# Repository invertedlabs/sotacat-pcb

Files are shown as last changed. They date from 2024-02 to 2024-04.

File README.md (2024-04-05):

# SOTAcat PCB

This project creates a SOTAcat PCB designed in [KiCad](https://www.kicad.org) and compatible with Brian AB6D's [SOTAcat](https://github.com/SOTAmat/SOTAcat) and [SOTAMAT](https://sotamat.com/) ("SOTA-Mate") web service and software. Brian provides a cloud service and iOS and Android which can interface with SOTAcat hardware to command an Elecraft KX2 or KX3 to transmit SOTA or POTA spots from the field via the FT8 spotting networks.  [The SOTAcat software](https://github.com/SOTAmat/) by Brian and Jeff KC6X also has other great features like a web interface that polls SOTA and POTA spots from their respective databases and commands the KX2 or KX3 to the spot frequency and mode with a single click.

This repository contains hardware files only. These files are available in zipped gerber form under "releases" which can be uploaded to PCB board manufacturers like [OshPark](https://www.oshpark.com), [JLCPCB](https://www.jlcpcb.com), or [PCBWay](https://www.pcbway.com) for quick turn around prototype-quantity builds.

# Attribution

A lot of folks from the SOTA community have contributed to this project.  For full attribution, see [the attribution list](https://github.com/SOTAmat/SOTAcat?tab=readme-ov-file#attribution) in the software repository. 

Specifically, this project wouldn't have been possible without the great SOTAmat software and original SOTAcat concept by Brian Mathews AB6D, the SOTAcat software authored primarily by Brian and Jeff Kowalski KC6X, and timely feedback from Brian, Jeff, and Rex Vokey KE6MT during the hardware design phase.

# Bill of Materials

A full BOM will be uploaded in due time, for now, refer to the schematic documents for build information, including part numbers for ordering from suppliers like [DigiKey](https://www.digikey.com) or [Mouser](https://www.mouser.com).

# Batteries

SOTAcat is a battery powered device. The battery is charged via a USB-C port.  Under the hood, a Seeeed XIAO ESP32-C3 board provides the USB port and battery charging circuitry. The battery is charged at 350mA, which limits the battery selection to batteries that can safely accept this amount of current. Most single-cell batteries above 300mAh will do fine given the bettery isn't allowed to overheat when charging. While many LiPo batteries are limited to 1C charging, test show that with a 300mAh battery the time spent above 1C is very brief, generally less than 10 minutes with a fully dead battery. Even so, the PCB can get warm during the charging process, and steps should be made to keep the battery and PCB cool during charging. This can be done by keeping the thermal paths between the PCB and the battery to a miniumum (e.g. don't tape them directly together without an insulating layer), and only charging an enclosed device at room temperature (<80 deg F, or <27 deg C).  

As with all LiPo batteries, *always monitor the device while charging* and don't leave the device charging in very hot conditions such as a car on a warm day.

More information will be forthcoming about which batteries we have tested and recommend. If purchasing a battery, connectors have been provided on v0.3 for both TinyCircuits batteries and KBT batteries. Check the schematic and layout for pinout information.

# Antenna

A wifi antenna needs to be attached to the XIAO ESP32-C3 module using the U.FL connector on that PCB (between the buttons).  Most XIAO ESP32-C3 purchases will include a flexible WiFI antenna. Other antennas have been tested and may be preferable in some cases (like when using a 3D printed case). Specifics TBD. 

# 3D Printed Cases

A number of 3D printed cases have been developed alongside this hardware by Justin K5EM (@poyting).  These files will also be posted and made available in time. If you want to build one before this happens, just reach out to @poynting.

# Changelog

v0.3 updates:
* Move the serial TX pin to the KXx interface to a pin without bootloader messages.
* Add transistor-based level conversion / inversion to the serial lines in both directions, improving robustness of the serial communications and removing the need for software serial port inversion.
* Add a battery monitor IC with a coulomb counter to improve the robustness of the battery level indicator. This is active even with the power switch off and causes ~5uA of battery drain. 
* Change form factor slightly by moving KXx plug to the corner of the board. This opens up room on the KX2 so that the SOTAcat doesn't block the key port in most cases.

v0.2 was a very quick turn PCB that translated AB6D's schematic to a PCB. v0.2 has some issues, notably that the TRRS R2 and Shield pins need to be tied together for working serial, and EFUSEs need to be set on the XIAO ESP32-C3 to limit the debug output on the pin used for KXx serial communications. With these changes, the device is very functional.

# Warranties (and lack thereof)

No warranties are expressed or implied by Jutin McAllister or InvertedLabs, LLC for the hardware in this repository. All files and information are provided as is, with all faults, and may not be suitable for any purpose.  While a best-faith effort has been taken to test these designs, they may cause damage to connected equipment. Some designs may be untested, and may not work as provided. Lithium batteries are inherently dangerous and may cause personal injury and/or damage to property, even when used correctly. Always monitor batteries during charging and usage, and store batteries safely per the battery manufacturer's recommendations. Never charge batteries unattended, while sleeping, or when hot. If you're not comfortable, your batteries aren't comfortable. Proceed with caution, use at your own risk.

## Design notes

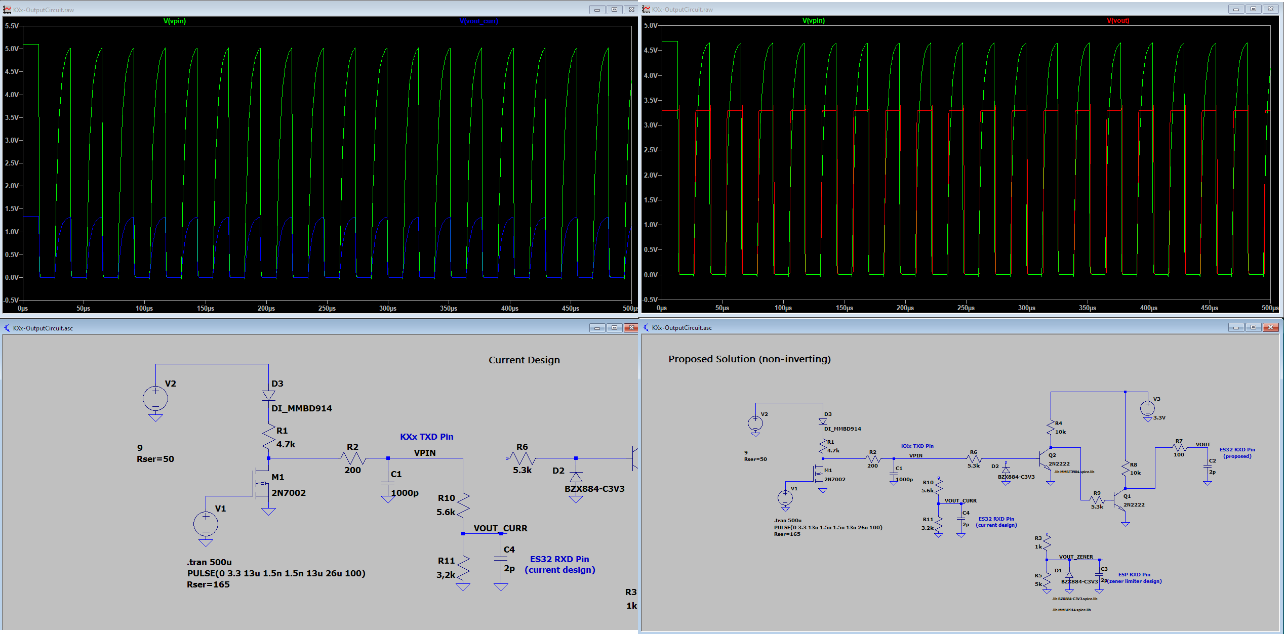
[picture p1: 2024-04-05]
InputCircuits.png

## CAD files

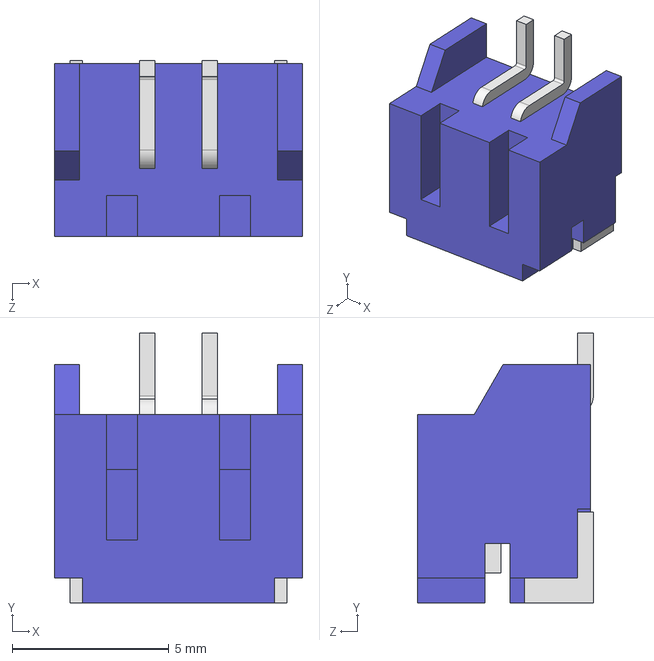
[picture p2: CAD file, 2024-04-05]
3DModels/S2B-PH-SM4-TB.step
7.90 x 8.60 x 5.60 mm

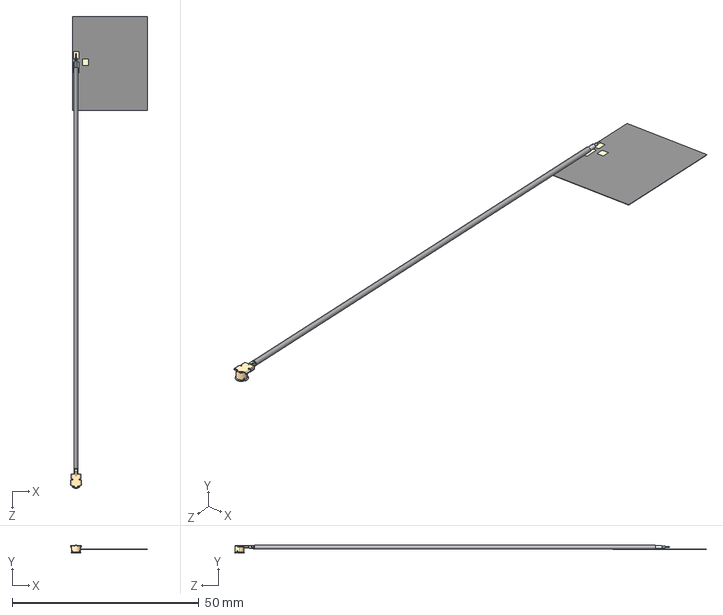
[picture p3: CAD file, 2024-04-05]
3DModels/ANT-2.4-FPC-SF100UF.STEP
20.7 x 2.19 x 126.5 mm
ANT-2.4-FPC-SH(SF)_SF
MHF 1 (2.1mm)

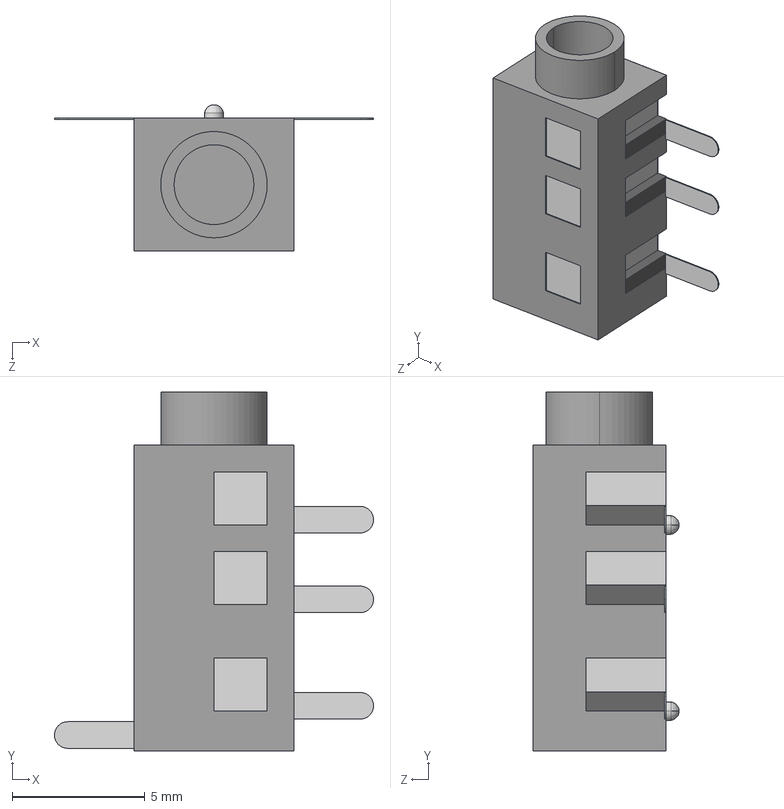
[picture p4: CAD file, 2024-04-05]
3DModels/PJ-320D-4A-audio_3.5mm_trrs.STEP
12.0 x 13.5 x 5.50 mm
Composant1.step
audio_3.5mm_trrs.step
audio_3.5mm_trrs-0.step
audio_3.5mm_trrs-1.step
audio_3.5mm_trrs-2.step
audio_3.5mm_trrs-3.step
audio_3.5mm_trrs-4.step
audio_3.5mm_trrs-5.step
audio_3.5mm_trrs-6.step
audio_3.5mm_trrs-7.step
audio_3.5mm_trrs-8.step
audio_3.5mm_trrs-9.step
audio_3.5mm_trrs-10.step
audio_3.5mm_trrs-11.step
audio_3.5mm_trrs-12.step
audio_3.5mm_trrs-13.step

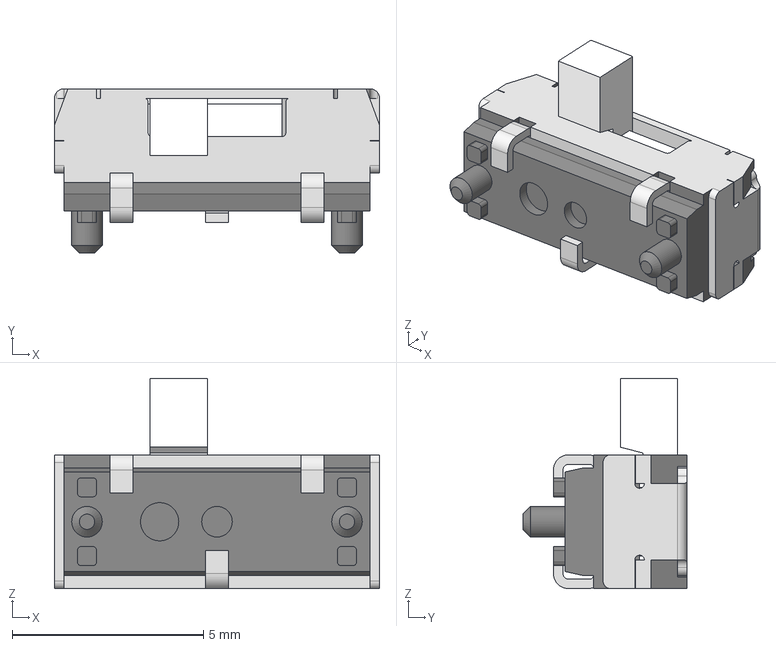
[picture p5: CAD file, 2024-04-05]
3DModels/CL-SB-12A-11T.stp
8.50 x 4.30 x 5.50 mm
2Side setting_s
12A-11_c

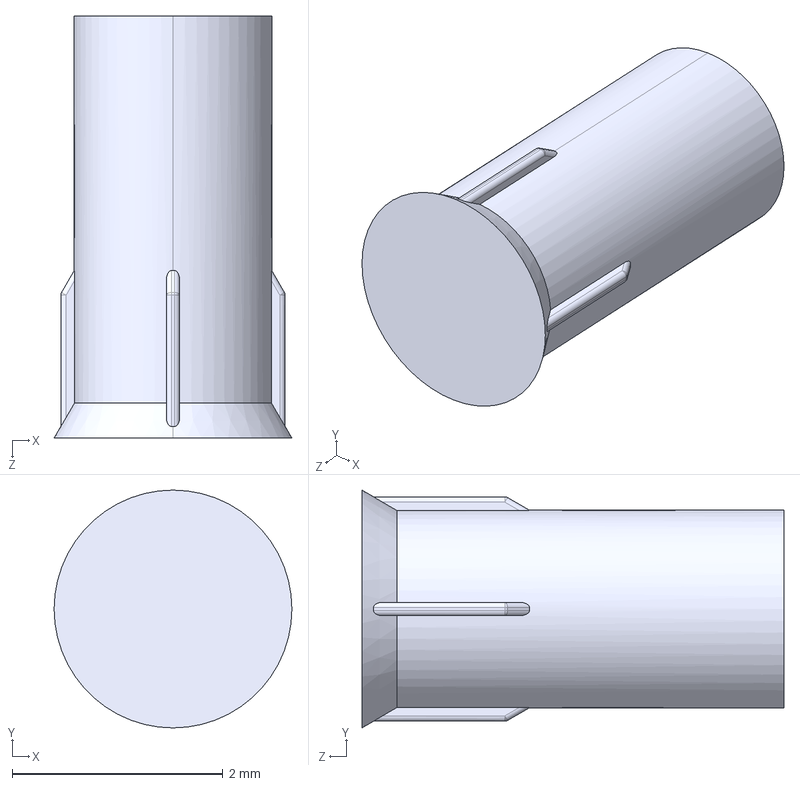
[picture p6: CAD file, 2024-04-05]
3DModels/LightPipe-PLPC2-4MM.step
2.25 x 2.25 x 4.00 mm

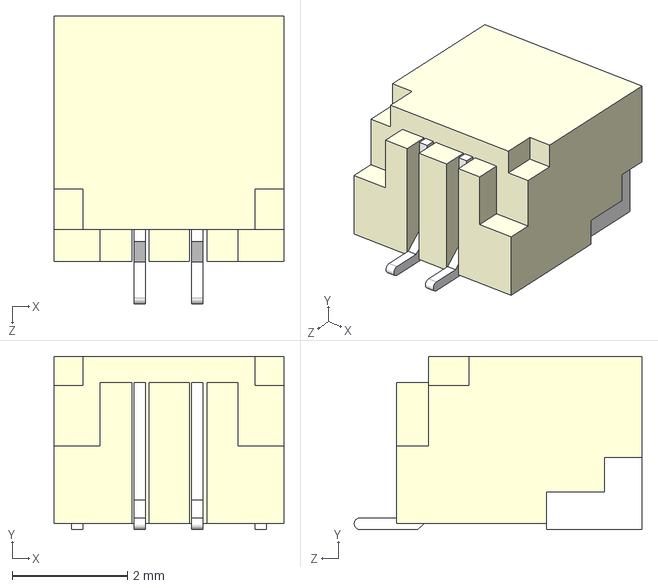
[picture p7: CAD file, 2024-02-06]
3DModels/JST_SM02B-SRSS-TB.step
3.99 x 3.00 x 4.99 mm

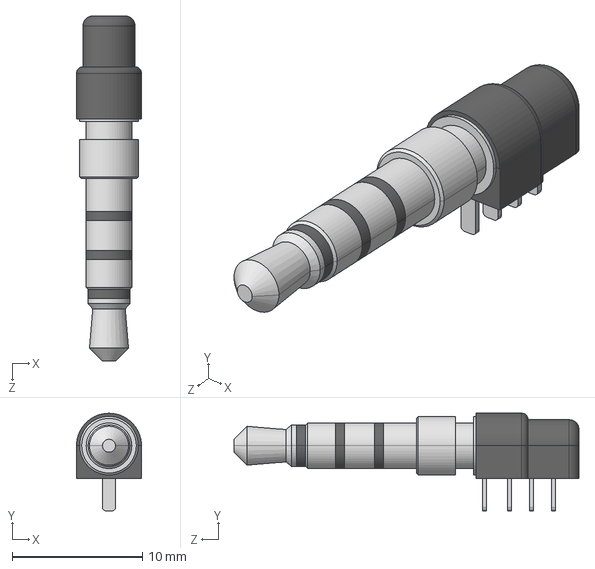
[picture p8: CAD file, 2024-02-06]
3DModels/54-00035.step
5.00 x 7.50 x 26.5 mm

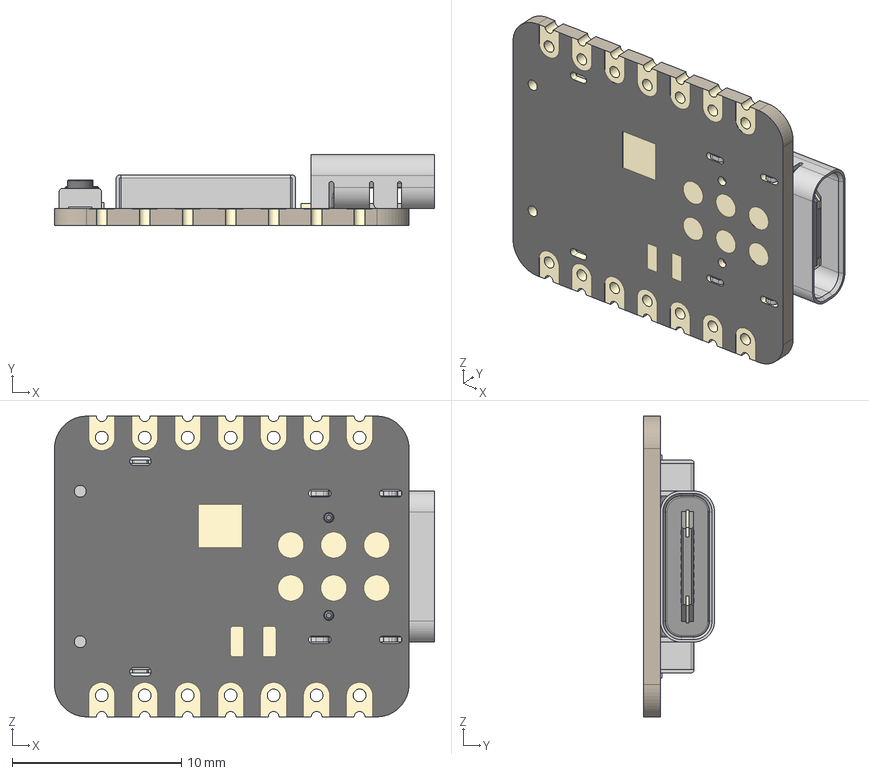
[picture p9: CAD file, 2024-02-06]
3DModels/Seeed Studio XIAO-ESP32-C3.step
22.5 x 4.21 x 17.8 mm
BOSS-EXTRUDE14_8_
BOSS-EXTRUDE7_4_
BOSS-EXTRUDE7_3_
BOSS-EXTRUDE14_4_
BOSS-EXTRUDE14_2_
BOSS-EXTRUDE14_11_
BOSS-EXTRUDE7_7_
BOSS-EXTRUDE14_9_
BOSS-EXTRUDE14_3_
BOSS-EXTRUDE14_7_
MIRROR2
BOSS-EXTRUDE14_5_
BOSS-EXTRUDE14_12_
BOSS-EXTRUDE7_8_
BOSS-EXTRUDE7_1_
BOSS-EXTRUDE14_10_
BOSS-EXTRUDE7_9_
BOSS-EXTRUDE14_6_
BOSS-EXTRUDE14_1_
BOSS-EXTRUDE7_6_
BOSS-EXTRUDE7_2_
CUT-EXTRUDE5
BOSS-EXTRUDE7_5_
U.FL Connector v1
Button (1) x 2
Shield

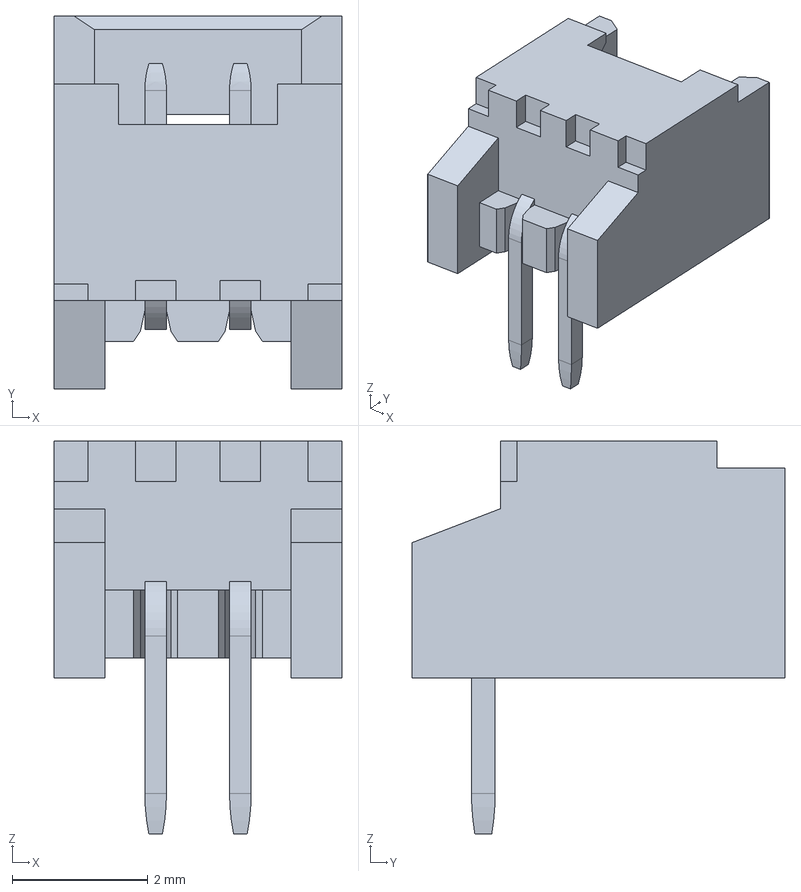
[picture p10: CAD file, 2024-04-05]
3DModels/530480210.stp
4.25 x 5.50 x 5.80 mm

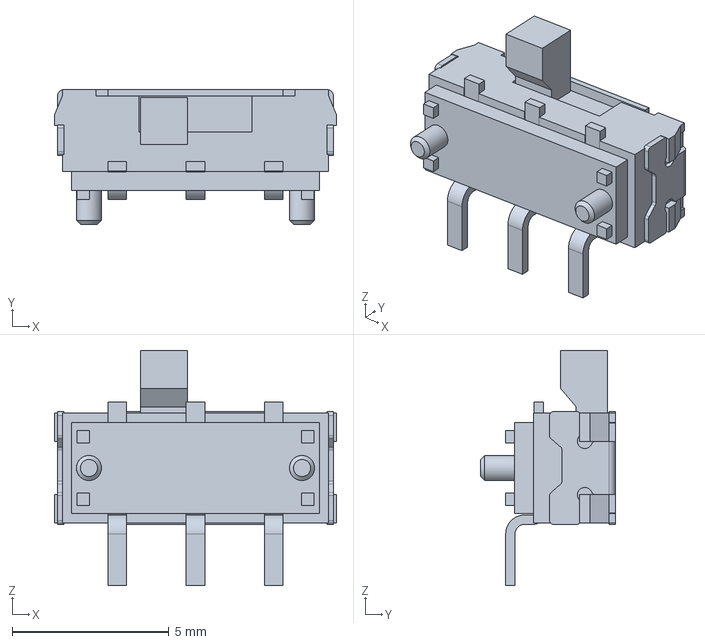
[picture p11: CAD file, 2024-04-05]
3DModels/JS102011SAQN.stp
9.00 x 4.30 x 7.50 mm

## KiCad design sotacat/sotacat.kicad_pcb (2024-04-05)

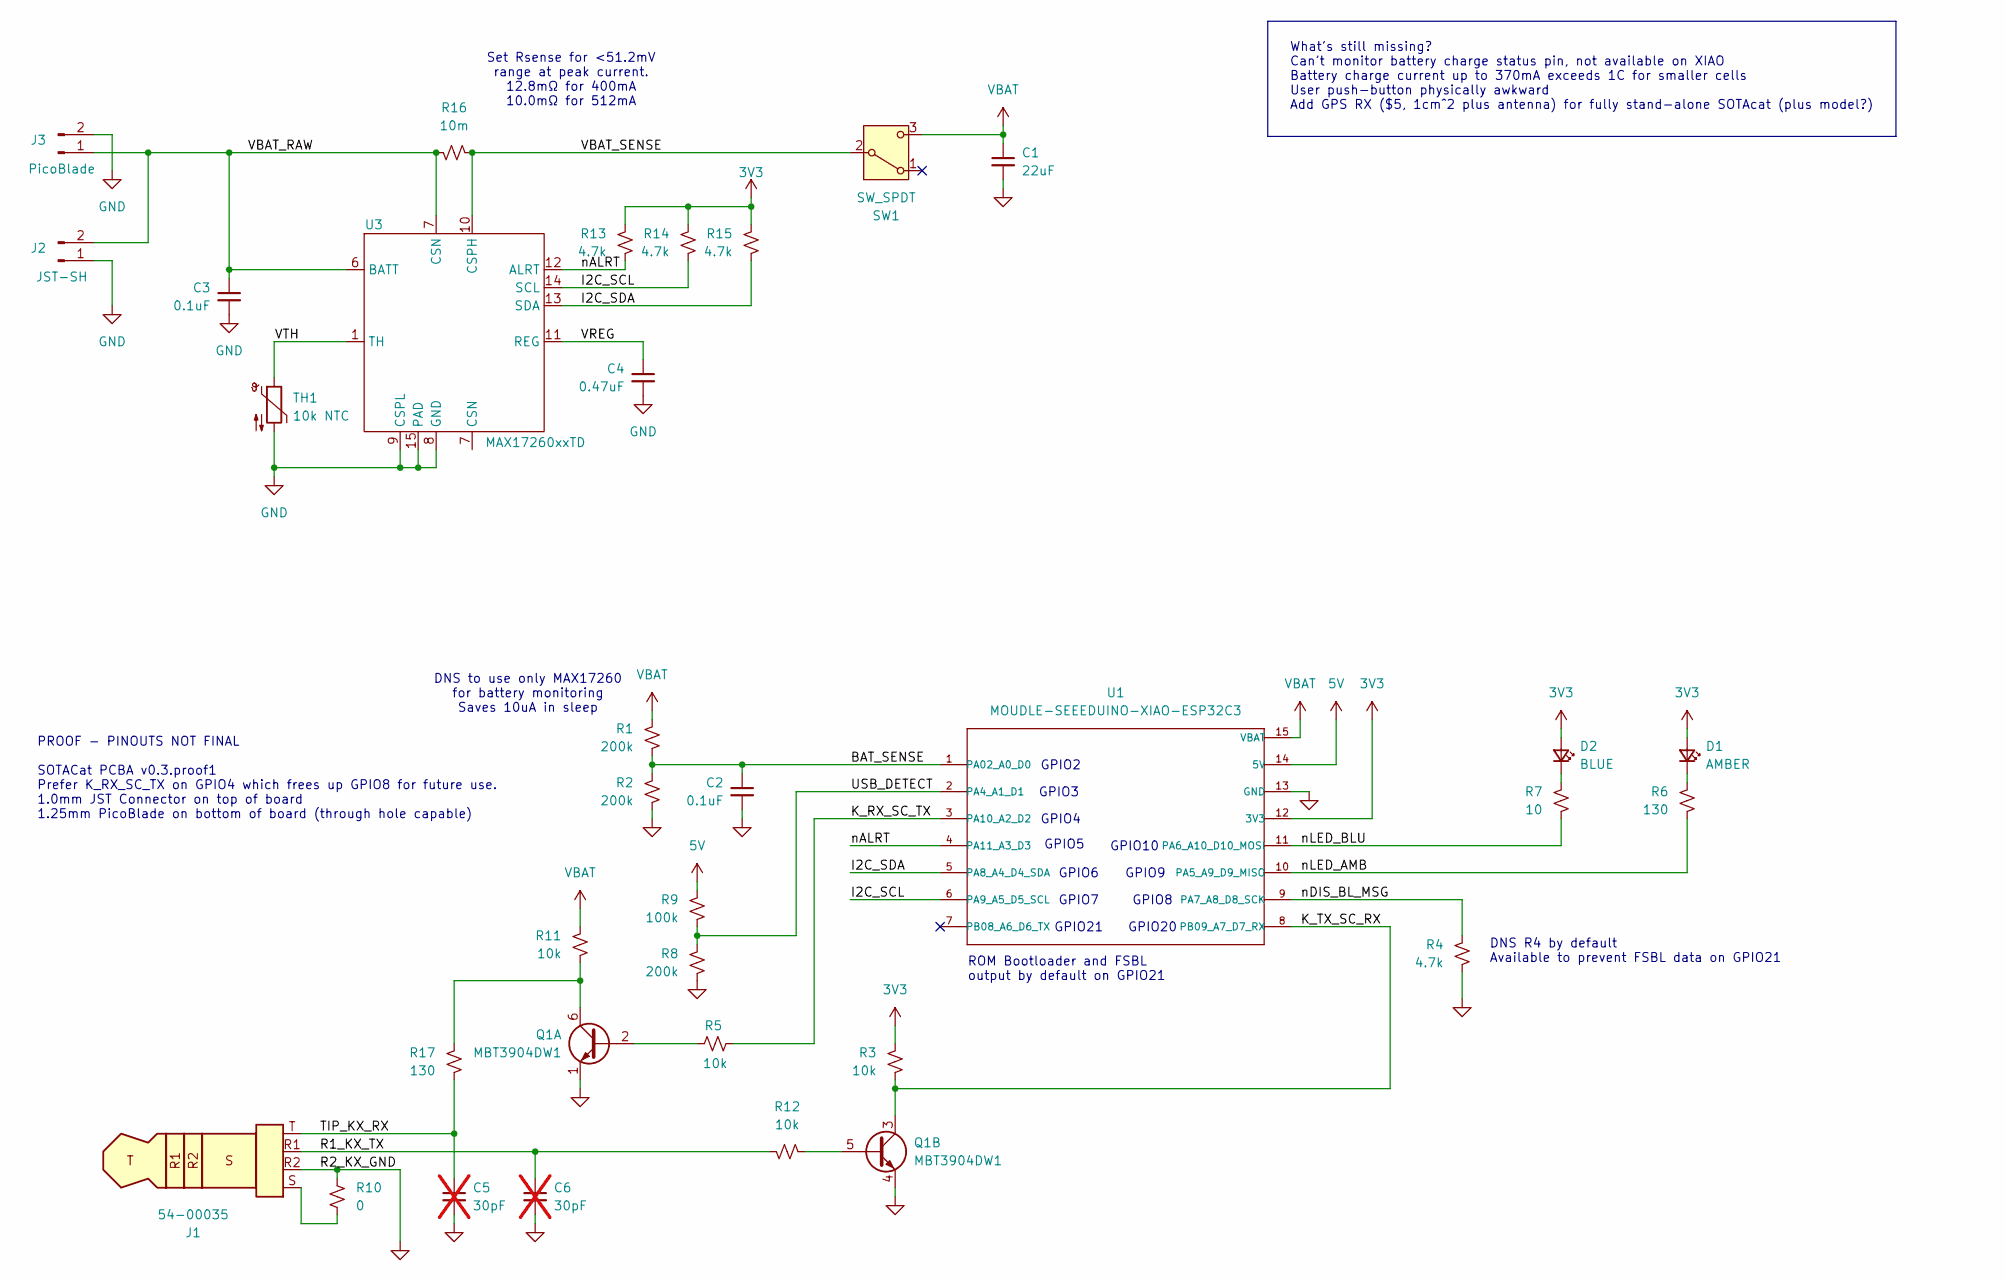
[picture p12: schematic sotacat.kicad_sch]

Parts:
C1: 22uF; C_1206_3216Metric; ManPartNo2 LMK316BJ226ML-T
C2, C3: 0.1uF; C_0603_1608Metric; ManPartNo KGM15AR70J104KM
C4: 0.47uF; C_0603_1608Metric; ManPartNo JMK107B7474KA-T
C5, C6: 30pF; C_0402_1005Metric; not fitted
D1: AMBER; LED_0603_1608Metric; ManPartNo 150060AS75000
D2: BLUE; LED_0603_1608Metric; ManPartNo 150060BS75000
J1: 54-00035; TENSILITY_54-00035
J2: JST-SH; JST_SH_SM02B-SRSS-TB_1x02-1MP_P1.00mm_Horizontal; ManPartNo SM02B-SRSS-TB
J3: PicoBlade; Molex_PicoBlade_53048-0210_1x02_P1.25mm_Horizontal; ManPartNo 0530480210
Q1: MBT3904DW1; SOT-363_SC-70-6; ManPartNo2 LMBT3904DW1T1G
R1, R2, R8: 200k; R_0603_1608Metric; ManPartNo RT0603DRE07200KL
R3, R5, R11, R12: 10k; R_0603_1608Metric; ManPartNo RT0603FRE0710KL
R4, R13, R14, R15: 4.7k; R_0603_1608Metric; ManPartNo RT0603DRE07200KL
R6, R17: 130; R_0603_1608Metric; ManPartNo RC0603FR-07130RL
R7: 10; R_0603_1608Metric; ManPartNo RC0603FR-0710RL
R9: 100k; R_0603_1608Metric; ManPartNo RT0603DRE07200KL
R10: 0; R_0603_1608Metric; ManPartNo RC0603FR-0710RL
R16: 10m; R_0603_1608Metric; ManPartNo RT0603DRE07200KL
SW1: SW_SPDT; SW_SPDT_CK-JS102011SAQN; ManPartNo JS102011SAQN
TH1: 10k NTC; R_0603_1608Metric; ManPartNo2 SDNT1608X103F3950FTF
U1: MOUDLE-SEEEDUINO-XIAO-ESP32C3; MOUDLE14P-SMD-2.54-21X17.8MM-VBAT; ManPartNo Seeed Technology Co., Ltd
U3: MAX17260xxTD; TDFN-14-1EP_3x3mm_P0.4mm_EP1.78x2.35mm; ManPartNo2 MAX17260SETD+

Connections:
3V3: D1.2 (A), D2.2 (A), R3.2, R13.1, R14.1, R15.1, U1.12 (3V3)
5V: R9.1, U1.14 (5V)
/BAT_SENSE: C2.1, R1.2, R2.1, U1.1 (PA02_A0_D0)
/I2C_SCL: R14.2, U1.6 (PA9_A5_D5_SCL), U3.14 (SCL)
/I2C_SDA: R15.2, U1.5 (PA8_A4_D4_SDA), U3.13 (SDA)
/K_RX_SC_TX: R5.2, U1.3 (PA10_A2_D2)
/K_TX_SC_RX: Q1.3 (C2), R3.1, U1.8 (PB09_A7_D7_RX)
/R1_KX_TX: C6.1, J1.R1, R12.2
/TIP_KX_RX: C5.1, J1.T, R17.2
/USB_DETECT: R8.1, R9.2, U1.2 (PA4_A1_D1)
/VBAT_RAW: C3.1, J2.2, J3.1, R16.1, U3.6 (BATT), U3.7 (CSN)
/VBAT_SENSE: R16.2, SW1.2 (B), U3.10 (CSPH)
/VREG: C4.1, U3.11 (REG)
/VTH: TH1.1, U3.1 (TH)
/nALRT: R13.2, U1.4 (PA11_A3_D3), U3.12 (ALRT)
/nDIS_BL_MSG: R4.1, U1.9 (PA7_A8_D8_SCK)
/nLED_AMB: R6.2, U1.10 (PA5_A9_D9_MISO)
/nLED_BLU: R7.2, U1.11 (PA6_A10_D10_MOSI)
GND: C1.2, C2.2, C3.2, C4.2, C5.2, C6.2, J1.R2, J2.1, J2.MP, J3.2, Q1.1 (E1), Q1.4 (E2), R2.2, R4.2, R8.2, R10.2, TH1.2, U1.13 (GND), U3.8 (GND), U3.9 (CSPL), U3.15 (PAD)
unnamed: D1.1 (K), R6.1
unnamed: D2.1 (K), R7.1
unnamed: J1.S, R10.1
unnamed: Q1.2 (B1), R5.1
unnamed: Q1.6 (C1), R11.1, R17.1
unnamed: Q1.5 (B2), R12.1
VBAT: C1.1, R1.1, R11.2, SW1.3 (C), U1.15 (VBAT)

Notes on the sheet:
GPIO8
ROM Bootloader and FSBL output by default on GPIO21
PROOF - PINOUTS NOT FINAL SOTACat PCBA v0.3.proof1 Prefer K_RX_SC_TX on GPIO4 which frees up GPIO8 for future use. 1.0mm JST Connector on top of board 1.25mm PicoBlade on bottom of board (through hole capable)
DNS R4 by default Available to prevent FSBL data on GPIO21
Set Rsense for <51.2mV range at peak current. 12.8mΩ for 400mA 10.0mΩ for 512mA
GPIO6
GPIO5
What's still missing? Can't monitor battery charge status pin, not available on XIAO Battery charge current up to 370mA exceeds 1C for smaller cells User push-button physically awkward Add GPS RX ($5, 1cm^2 plus antenna) for fully stand-alone SOTAcat (plus model?)
GPIO2
DNS to use only MAX17260 for battery monitoring Saves 10uA in sleep
GPIO3
GPIO9
GPIO4
GPIO7
GPIO20
GPIO21
GPIO10

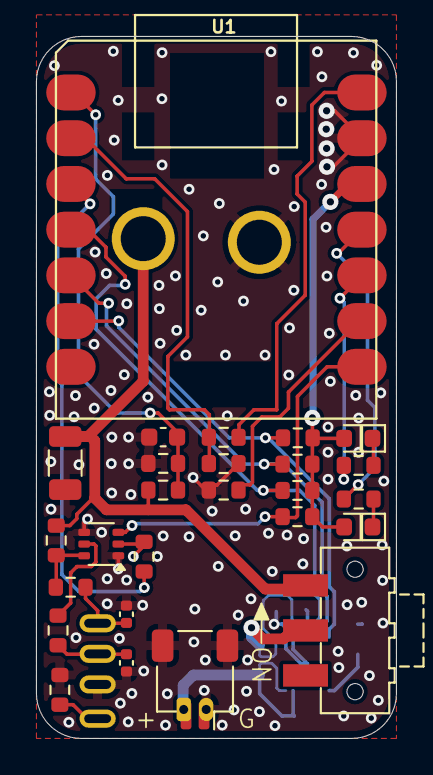
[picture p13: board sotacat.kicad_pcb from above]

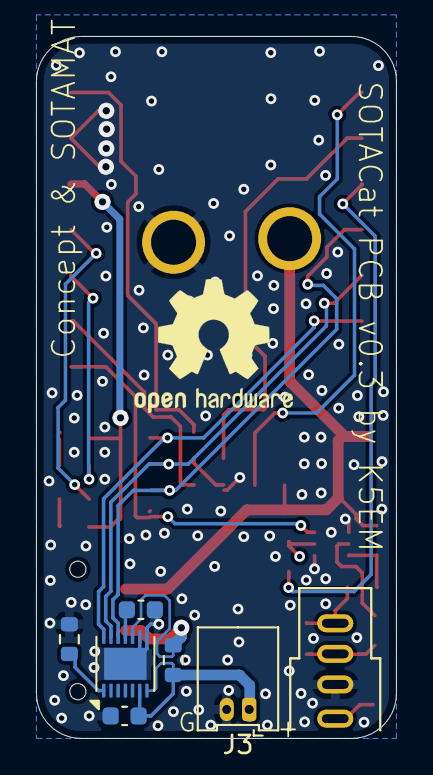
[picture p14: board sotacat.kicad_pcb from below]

Board: 2 copper layers, 20.0 x 39.0 mm, 33 parts (7 on the bottom side), 26 nets.

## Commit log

2024-02-06 Initial commit as built rev 0.2
    [54-00035.step, JST_SM02B-SRSS-TB.step, Seeed Studio XIAO-ESP32-C3.step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]
2024-02-06 v0.3 placement
    [sotacat.kicad_pcb, sotacat.kicad_sch]
2024-02-13 Just playing around with some v0.3 thoughts.
    [sotacat.kicad_pcb]
2024-03-08 Updates for Rev0.3. Breaking pin changes.
    [ANT-2.4-FPC-SF100UF.STEP, CL-SB-12A-11T.stp, JS102011SAQN.stp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]
2024-04-05 PCB v0.3. Added MAX17260xxTD battery monitor, moved plug to corner, moved switch and LEDs accordingly. Changed pinout. Pinout not compatible with v0.2 due to TX data swap to avoid bootloader output.
    [530480210.stp, sotacat.kicad_pcb, sotacat.kicad_sch]
2024-04-05 v0.3 after closing project.
    [sotacat.kicad_pcb]

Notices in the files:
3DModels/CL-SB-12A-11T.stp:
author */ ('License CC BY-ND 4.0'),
